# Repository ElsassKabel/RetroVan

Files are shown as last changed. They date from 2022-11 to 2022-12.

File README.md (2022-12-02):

# RetroVan
🚐 *Retro style [Minivan](https://trashman.wiki/keyboards/minivan) keyboard*







| Front side | Back side |
| ----- | ----- |
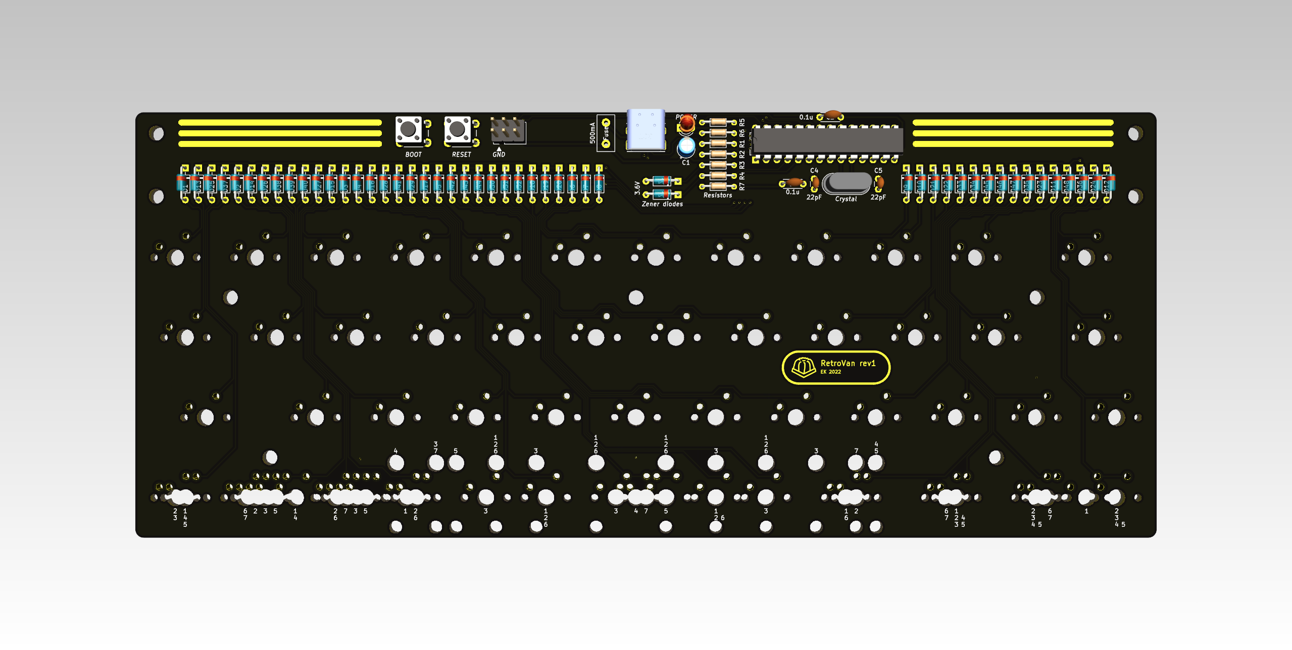
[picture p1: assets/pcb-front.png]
Front side
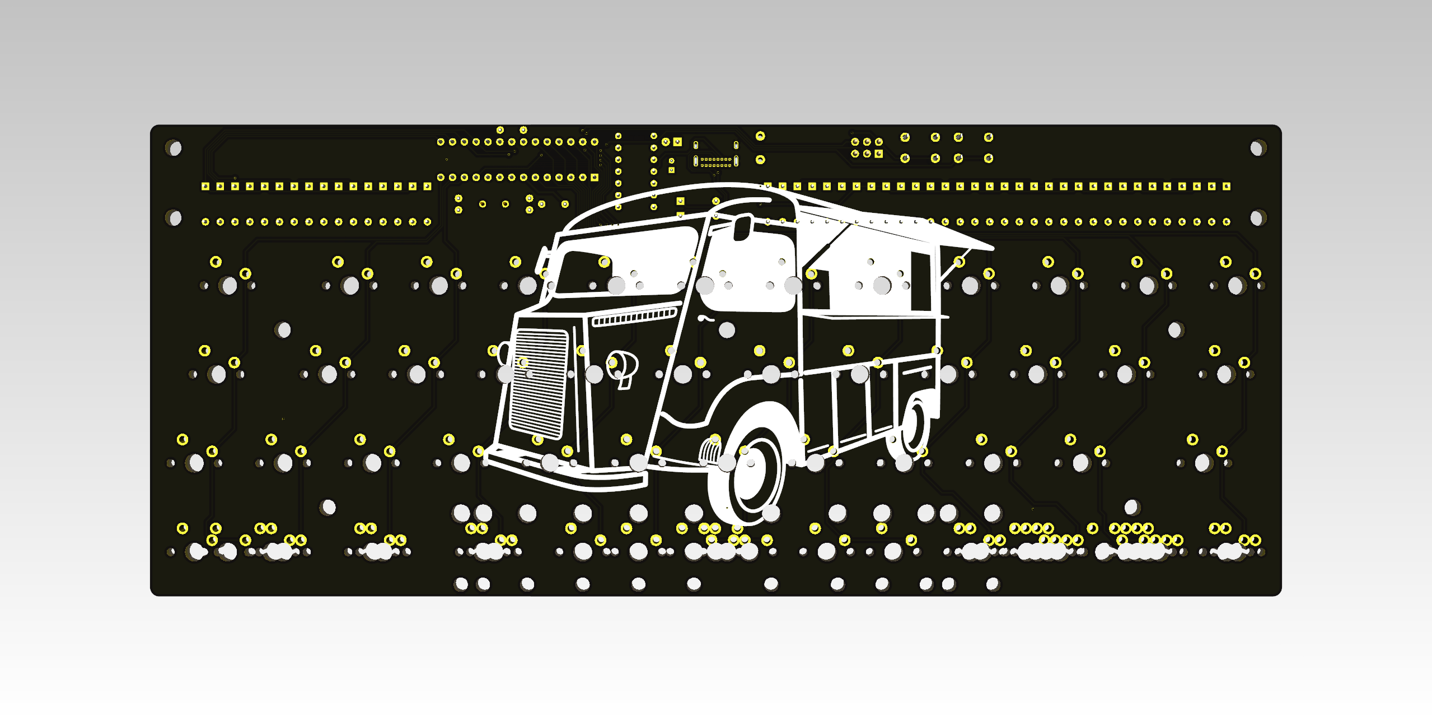
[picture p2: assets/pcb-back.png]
Back side
|  |  |

<!-- ## ✨ Pros:

- 🌈 Easy to customize with QMK and Vial
- 💅 Compact and beautiful
- 🦄 Open source -->

## 📖 Documentation

*🚧 WIP*

| Name | Supported layout |
| ----- | ----- |
| A | 1, 2 |
| B | 3, 4, 5 |
| C | 6, 7 |

<!-- ## 👀 Showcase -->

## 👤 Author

**LucasAlt**
* Website: https://www.lucasalt.fr
* Twitter: [@LucasCtrlAlt](https://twitter.com/LucasCtrlAlt)
* GitHub: [@LucasCtrl](https://github.com/LucasCtrl)

<!-- ## 🙏 Thanks
* [**@username**](https://github.com/username) - What I do
* [And many more!](https://github.com/ElsassKabel/RetroVan/graphs/contributors) -->

## 🤝 Contributing

<!-- Before contributing to this project, make sure you have read the [contribution guidelines](https://github.com/ElsassKabel/RetroVan/blob/main/CONTRIBUTING.md)! -->

1. Fork it (https://github.com/ElsassKabel/RetroVan/fork)
2. Create your feature branch (`git checkout -b feature/fooBar`)
3. Commit your changes (`git commit -am 'Add some fooBar'`)
4. Push to the branch (`git push origin feature/fooBar`)
5. Create a new Pull Request

## Show your support

- Give a ⭐️ if you like this project!

<!-- <a href="https://www.buymeacoffee.com/lucasalt"><img src="https://img.buymeacoffee.com/button-api/?text=Buy me a coffee&emoji=&slug=lucasalt&button_colour=5F7FFF&font_colour=ffffff&font_family=Poppins&outline_colour=000000&coffee_colour=FFDD00"></a> -->

## 📝 License

This project is open source and available under the [MIT License](https://github.com/ElsassKabel/RetroVan/blob/main/LICENSE.md)

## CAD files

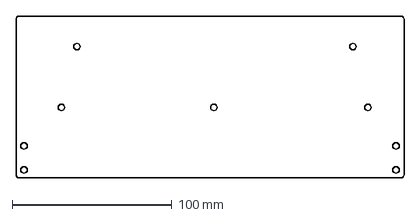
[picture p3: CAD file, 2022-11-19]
pcb/pcb.dxf
242.9 x 101.2 mm

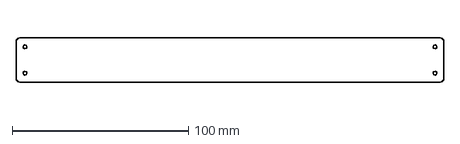
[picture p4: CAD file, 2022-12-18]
plates/cover.dxf
242.9 x 25.0 mm

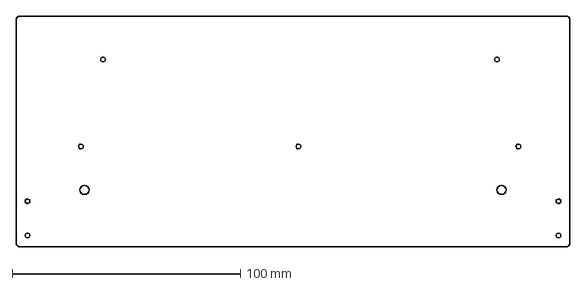
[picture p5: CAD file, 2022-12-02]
plates/backPlate.dxf
242.9 x 101.2 mm

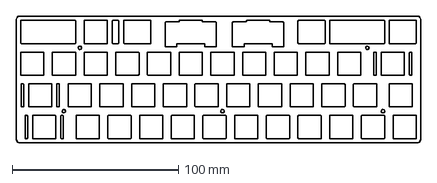
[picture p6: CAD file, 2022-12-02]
plates/plateA.dxf
242.9 x 76.2 mm

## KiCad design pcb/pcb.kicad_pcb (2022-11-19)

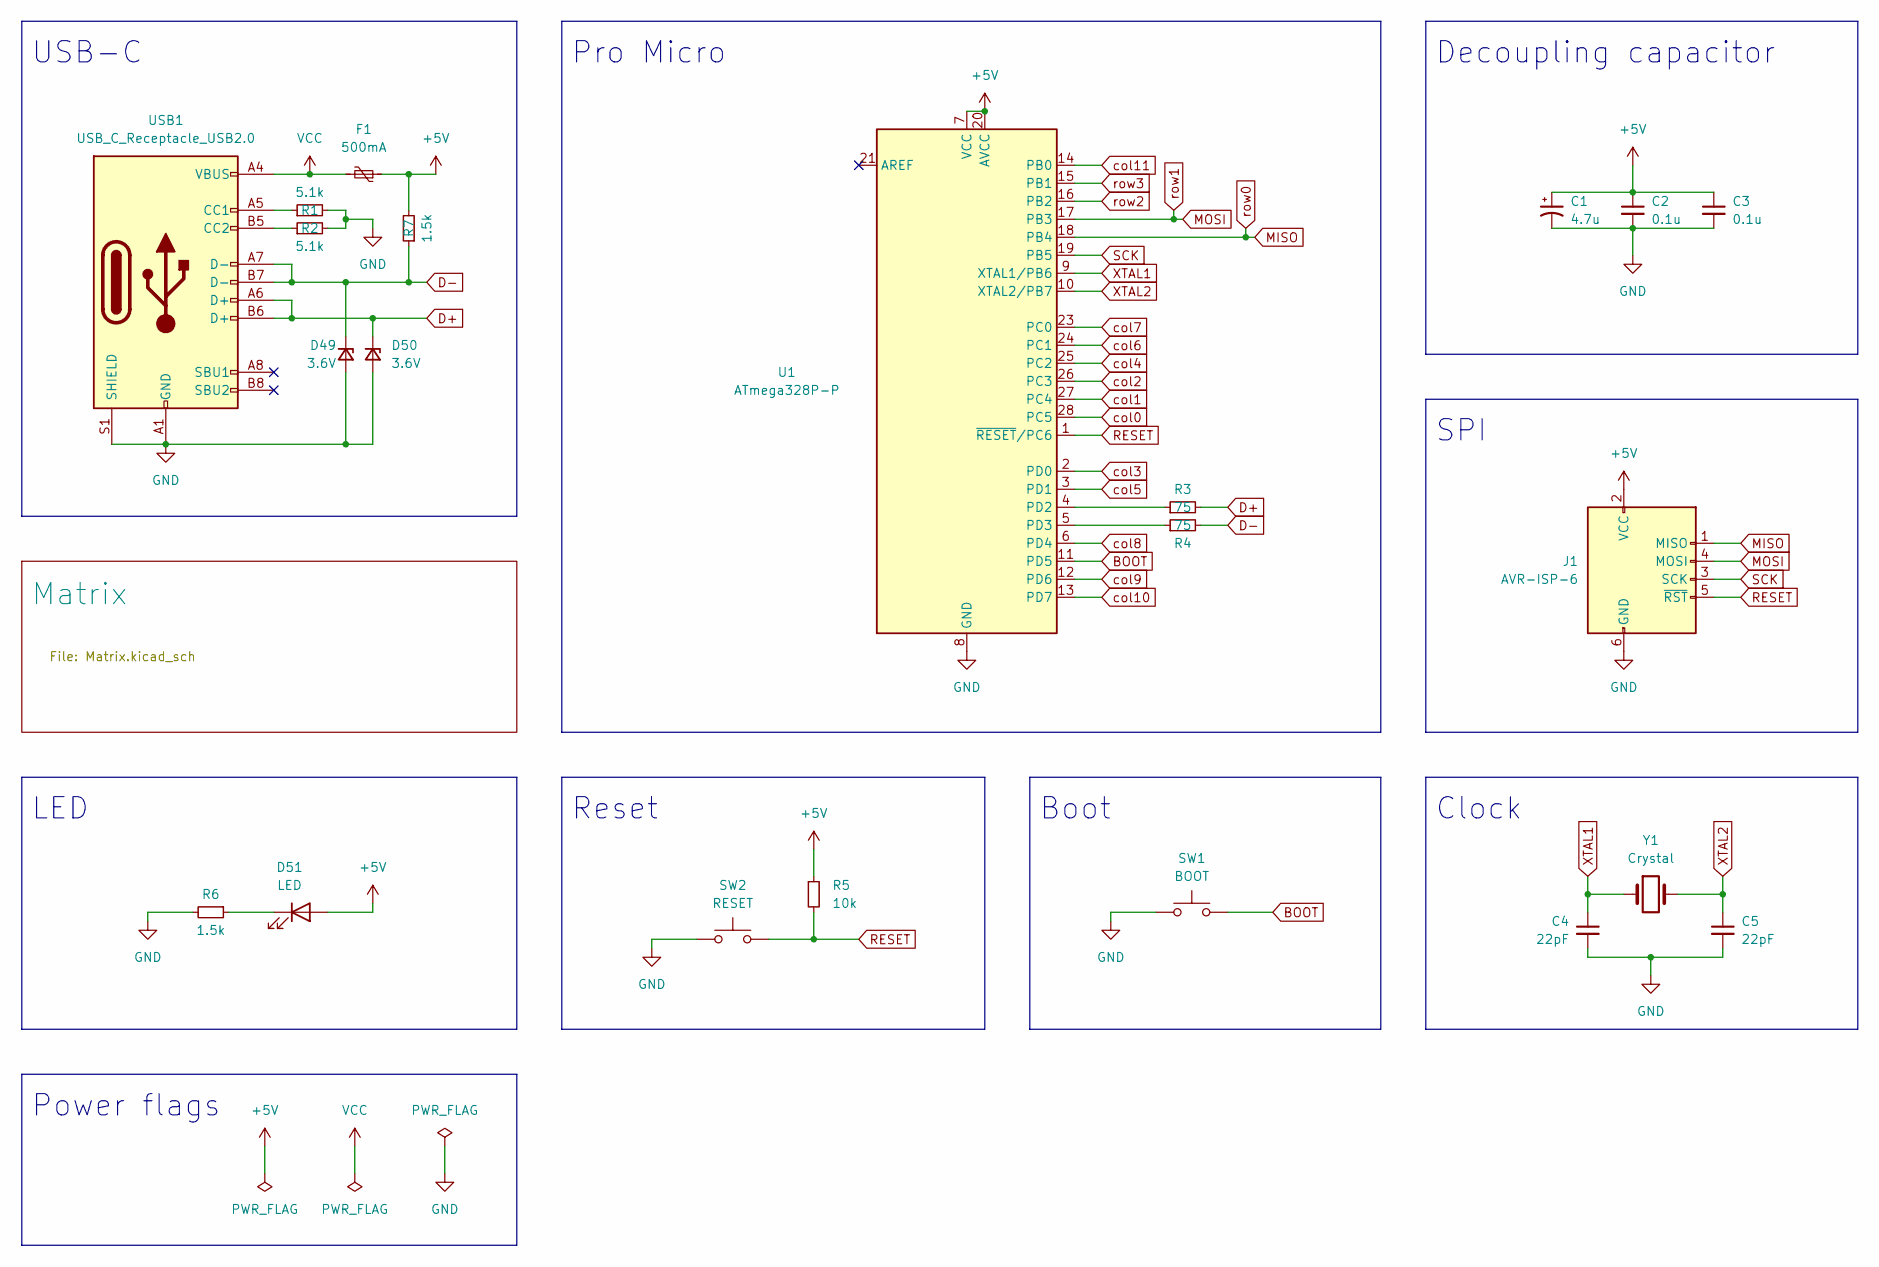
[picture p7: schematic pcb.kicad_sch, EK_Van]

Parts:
C1: 4.7u; CP_Radial_D4.0mm_P2.00mm
C2, C3: 0.1u; C_Disc_D4.3mm_W1.9mm_P5.00mm
C4, C5: 22pF; C_Disc_D3.0mm_W1.6mm_P2.50mm
D49, D50: 3.6V; D_DO-35_SOD27_P7.62mm_Horizontal
D51: LED; LED_D3.0mm
F1: 500mA; Fuse_Littelfuse_395Series
J1: AVR-ISP-6; PinHeader_2x03_P2.54mm_Vertical
R1, R2: 5.1k; R_Axial_DIN0204_L3.6mm_D1.6mm_P7.62mm_Horizontal
R3, R4: 75; R_Axial_DIN0204_L3.6mm_D1.6mm_P7.62mm_Horizontal
R5: 10k; R_Axial_DIN0204_L3.6mm_D1.6mm_P7.62mm_Horizontal
R6, R7: 1.5k; R_Axial_DIN0204_L3.6mm_D1.6mm_P7.62mm_Horizontal
SW1: BOOT; SW_PUSH_6mm
SW2: RESET; SW_PUSH_6mm
U1: ATmega328P-P; DIP-28_W7.62mm
USB1: USB_C_Receptacle_USB2.0; USB_C_GCT_USB4085
Y1: Crystal; Crystal_HC49-4H_Vertical

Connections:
+5V: C1.1, C2.1, C3.1, D51.2 (A), F1.1, J1.2 (VCC), R5.1, R7.2, U1.7 (VCC), U1.20 (AVCC)
BOOT: SW1.2, U1.11 (PD5)
D+: D50.1 (K), R3.2, USB1.A6 (D+), USB1.B6 (D+)
D-: D49.1 (K), R4.2, R7.1, USB1.A7 (D-), USB1.B7 (D-)
GND: C1.2, C2.2, C3.2, C4.2, C5.2, D49.2 (A), D50.2 (A), J1.6 (GND), R1.2, R2.2, R6.2, SW1.1, SW2.1, U1.8 (GND), U1.22 (GND), USB1.A1 (GND), USB1.A12 (GND), USB1.B1 (GND), USB1.B12 (GND), USB1.S1 (SHIELD)
MISO: J1.1 (MISO), U1.18 (PB4); also elsewhere on the board
MOSI: J1.4 (MOSI), U1.17 (PB3); also elsewhere on the board
unnamed: D51.1 (K), R6.1
unnamed: R1.1, USB1.A5 (CC1)
unnamed: R2.1, USB1.B5 (CC2)
unnamed: R3.1, U1.4 (PD2)
unnamed: R4.1, U1.5 (PD3)
RESET: J1.5 (~RST), R5.2, SW2.2, U1.1 (~RESET/PC6)
SCK: J1.3 (SCK), U1.19 (PB5)
VCC: F1.2, USB1.A4 (VBUS), USB1.A9 (VBUS), USB1.B4 (VBUS), USB1.B9 (VBUS)
XTAL1: C4.1, U1.9 (XTAL1/PB6), Y1.1
XTAL2: C5.1, U1.10 (XTAL2/PB7), Y1.2
col0: U1.28 (PC5); also elsewhere on the board
col1: U1.27 (PC4); also elsewhere on the board
col2: U1.26 (PC3); also elsewhere on the board
col3: U1.2 (PD0); also elsewhere on the board
col4: U1.25 (PC2); also elsewhere on the board
col5: U1.3 (PD1); also elsewhere on the board
col6: U1.24 (PC1); also elsewhere on the board
col7: U1.23 (PC0); also elsewhere on the board
col8: U1.6 (PD4); also elsewhere on the board
col9: U1.12 (PD6); also elsewhere on the board
col10: U1.13 (PD7); also elsewhere on the board
col11: U1.14 (PB0); also elsewhere on the board
row2: U1.16 (PB2); also elsewhere on the board
row3: U1.15 (PB1); also elsewhere on the board

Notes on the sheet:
LED
Power flags
SPI
Pro Micro
Decoupling capacitor
Clock
Boot
USB-C
Reset

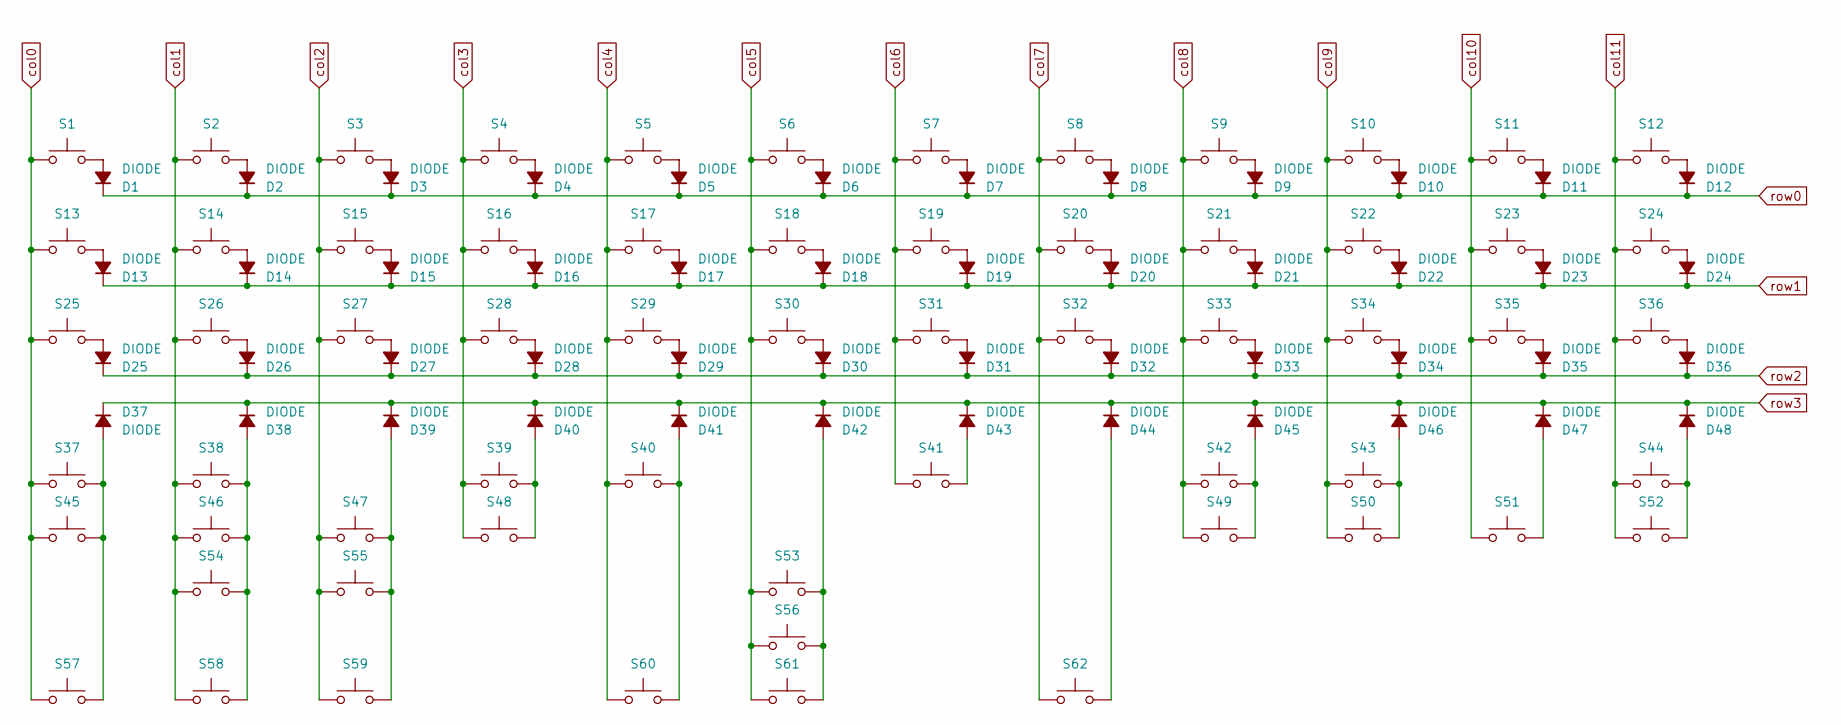
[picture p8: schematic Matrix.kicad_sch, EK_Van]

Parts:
D1, D2, D3, D4, D5, D6, D7, D8, D9, D10, D11, D12, D13, D14, D15, D16, D17, D18, D19, D20, D21, D22, D23, D24, D25, D26, D27, D28, D29, D30, D31, D32, D33, D34, D35, D36, D37, D38, D39, D40, D41, D42, D43, D44, D45, D46, D47, D48: DIODE; D_DO-35_SOD27_P7.62mm_Horizontal
S1, S2, S3, S4, S5, S6, S7, S8, S9, S10, S11, S14, S15, S16, S17, S18, S19, S20, S21, S22, S23, S26, S27, S28, S29, S30, S31, S32, S33, S34, S35, S36, S45, S46, S47, S48, S50, S51, S52, S54, S57, S59, S61: SWITCH_2PIN; SW_Cherry_MX_PCB_1.00u
S12, S25, S44: SWITCH_2PIN; SW_Cherry_MX_PCB_1.75u
S13, S37, S39, S42, S55, S58: SWITCH_2PIN; SW_Cherry_MX_PCB_1.25u
S24, S38, S43, S49: SWITCH_2PIN; SW_Cherry_MX_PCB_1.50u
S40, S60: SWITCH_2PIN; SW_Cherry_MX_PCB_2.25u
S41: SWITCH_2PIN; SW_Cherry_MX_PCB_2.00u
S53: SWITCH_2PIN; SW_Cherry_MX_PCB_6.25u
S56: SWITCH_2PIN; SW_Cherry_MX_PCB_7.00u
S62: SWITCH_2PIN; SW_Cherry_MX_PCB_2.75u

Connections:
MISO: D1.1 (K), D2.1 (K), D3.1 (K), D4.1 (K), D5.1 (K), D6.1 (K), D7.1 (K), D8.1 (K), D9.1 (K), D10.1 (K), D11.1 (K), D12.1 (K); also elsewhere on the board
MOSI: D13.1 (K), D14.1 (K), D15.1 (K), D16.1 (K), D17.1 (K), D18.1 (K), D19.1 (K), D20.1 (K), D21.1 (K), D22.1 (K), D23.1 (K), D24.1 (K); also elsewhere on the board
unnamed: D1.2 (A), S1.2
unnamed: D2.2 (A), S2.2
unnamed: D3.2 (A), S3.2
unnamed: D4.2 (A), S4.2
unnamed: D5.2 (A), S5.2
unnamed: D6.2 (A), S6.2
unnamed: D7.2 (A), S7.2
unnamed: D8.2 (A), S8.2
unnamed: D9.2 (A), S9.2
unnamed: D10.2 (A), S10.2
unnamed: D11.2 (A), S11.2
unnamed: D12.2 (A), S12.2
unnamed: D13.2 (A), S13.2
unnamed: D14.2 (A), S14.2
unnamed: D15.2 (A), S15.2
unnamed: D16.2 (A), S16.2
unnamed: D17.2 (A), S17.2
unnamed: D18.2 (A), S18.2
unnamed: D19.2 (A), S19.2
unnamed: D20.2 (A), S20.2
unnamed: D21.2 (A), S21.2
unnamed: D22.2 (A), S22.2
unnamed: D23.2 (A), S23.2
unnamed: D24.2 (A), S24.2
unnamed: D25.2 (A), S25.2
unnamed: D26.2 (A), S26.2
unnamed: D27.2 (A), S27.2
unnamed: D28.2 (A), S28.2
unnamed: D29.2 (A), S29.2
unnamed: D30.2 (A), S30.2
unnamed: D31.2 (A), S31.2
unnamed: D32.2 (A), S32.2
unnamed: D33.2 (A), S33.2
unnamed: D34.2 (A), S34.2
unnamed: D35.2 (A), S35.2
unnamed: D36.2 (A), S36.2
unnamed: D37.2 (A), S37.2, S45.2, S57.2
unnamed: D38.2 (A), S38.2, S46.2, S54.2, S58.2
unnamed: D39.2 (A), S47.2, S55.2, S59.2
unnamed: D40.2 (A), S39.2, S48.2
unnamed: D41.2 (A), S40.2, S60.2
unnamed: D42.2 (A), S53.2, S56.2, S61.2
unnamed: D43.2 (A), S41.2
unnamed: D44.2 (A), S62.2
unnamed: D45.2 (A), S42.2, S49.2
unnamed: D46.2 (A), S43.2, S50.2
unnamed: D47.2 (A), S51.2
unnamed: D48.2 (A), S44.2, S52.2
col0: S1.1, S13.1, S25.1, S37.1, S45.1, S57.1; also elsewhere on the board
col1: S2.1, S14.1, S26.1, S38.1, S46.1, S54.1, S58.1; also elsewhere on the board
col2: S3.1, S15.1, S27.1, S47.1, S55.1, S59.1; also elsewhere on the board
col3: S4.1, S16.1, S28.1, S39.1, S48.1; also elsewhere on the board
col4: S5.1, S17.1, S29.1, S40.1, S60.1; also elsewhere on the board
col5: S6.1, S18.1, S30.1, S53.1, S56.1, S61.1; also elsewhere on the board
col6: S7.1, S19.1, S31.1, S41.1; also elsewhere on the board
col7: S8.1, S20.1, S32.1, S62.1; also elsewhere on the board
col8: S9.1, S21.1, S33.1, S42.1, S49.1; also elsewhere on the board
col9: S10.1, S22.1, S34.1, S43.1, S50.1; also elsewhere on the board
col10: S11.1, S23.1, S35.1, S51.1; also elsewhere on the board
col11: S12.1, S24.1, S36.1, S44.1, S52.1; also elsewhere on the board
row2: D25.1 (K), D26.1 (K), D27.1 (K), D28.1 (K), D29.1 (K), D30.1 (K), D31.1 (K), D32.1 (K), D33.1 (K), D34.1 (K), D35.1 (K), D36.1 (K); also elsewhere on the board
row3: D37.1 (K), D38.1 (K), D39.1 (K), D40.1 (K), D41.1 (K), D42.1 (K), D43.1 (K), D44.1 (K), D45.1 (K), D46.1 (K), D47.1 (K), D48.1 (K); also elsewhere on the board

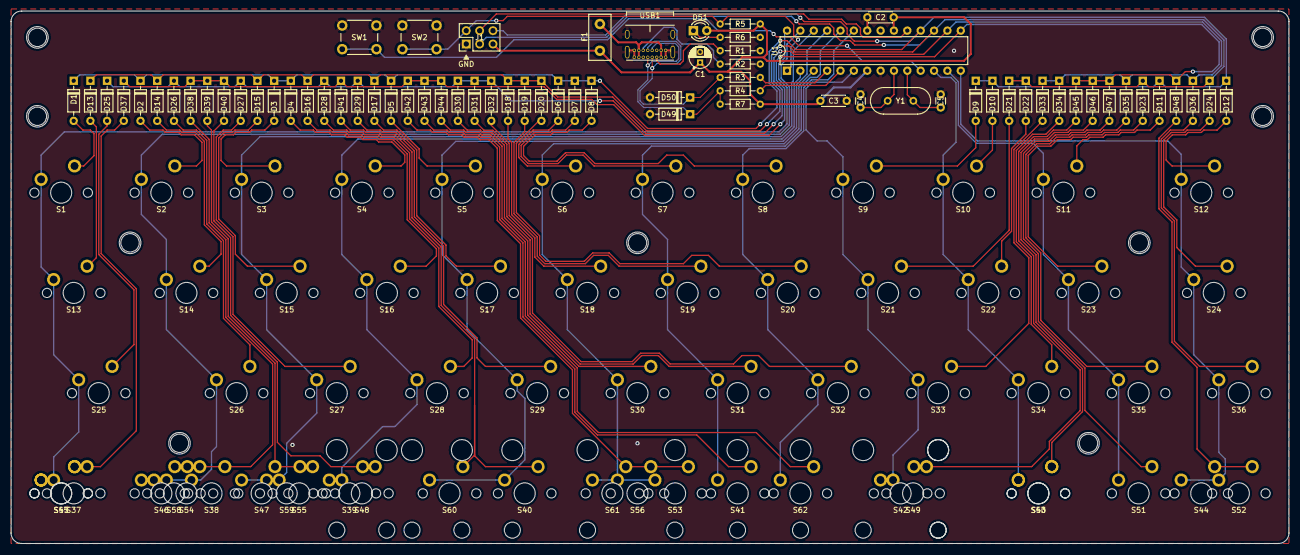
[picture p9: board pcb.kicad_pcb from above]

Board: 2 copper layers, 242.9 x 101.2 mm, 132 parts (0 on the bottom side), 79 nets.

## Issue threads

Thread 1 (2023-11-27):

Wrong hole position on the backplate

LucasCtrl, 2023-11-27:
The middle hole (in orange) is missed placed on the backplate. It don't allow the end-used to see the design on the backplate when she's mounted on the keyboard.

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

2 solutions:
- Move the hole slightly to the right
- Place the design at the back of the plate instead of the front

LucasCtrl, 2024-04-12:
Fixed with commit [6c212b5](https://github.com/ElsassKabel/RetroVan/commit/6c212b5cd2d38d71d309b18179abcec676024460)

Closed 2024-04-12.

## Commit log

2022-11-18 🎉 Initial commit
2022-11-18 🚧 WIP - Create PCB schematic - Start to place components on the PCB
    [Matrix.kicad_sch, pcb.kicad_pcb, pcb.kicad_sch]
2022-11-18 ➕ Add submodules
2022-11-18 🚧 Fixing diodes footprints issue
    [Matrix.kicad_sch, pcb.kicad_pcb, pcb.kicad_sch]
2022-11-19 ➖ Remove submodule
2022-11-19 🚧 WIP - Place the components - Wire all the components
    [Matrix.kicad_sch, pcb.dxf, pcb.kicad_pcb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]
2022-11-27 ⬆️ Update local footprints
2022-12-02 🏗️ Prepare for production
    [Matrix.kicad_sch, pcb.kicad_sch]
2022-12-02 ✨ Add plate A
    [plateA.dxf, plateA.kicad_pcb, plateA.kicad_sch]
2022-12-02 ✨ Add back plate
    [backPlate.dxf, backPlate.kicad_pcb, backPlate.kicad_sch]
2022-12-02 🚀 Add PCB gerber files
    [pcb-B_Cu.gbl, pcb-B_Mask.gbs, pcb-B_Paste.gbp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]
2022-12-02 🚀 Add plate A gerber files
    [plateA-B_Cu.gbl, plateA-B_Mask.gbs, plateA-B_Paste.gbp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]
2022-12-02 🚀 Add back plate gerber files
    [backPlate-B_Cu.gbl, backPlate-B_Mask.gbs, backPlate-B_Paste.gbp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]
2022-12-03 ✨ Add BOM
2022-12-18 ✨ Add cover plate
    [cover.dxf]
2023-01-02 🛠️ Update LED resistor value
    [pcb.kicad_sch]
